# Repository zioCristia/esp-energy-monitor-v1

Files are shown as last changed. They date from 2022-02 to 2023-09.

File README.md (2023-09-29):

# Esp energy monitor - Version 1
### There is a new and better [version](https://github.com/zioCristia/esp-energy-monitor-v2) of this board
Esp32 based module, 220V ac powered, energy monitor with two ct sensors for solar power and home power, and an LCD I2C display for visualization. Integrated with ESPhome in my IoT house based in Home Assistant.
Any possibility of improvement is accepted.

You can find a [video tutorial](https://www.youtube.com/watch?v=UY-CO4Zc2r0) (in italian) of this pcb on YouTube.

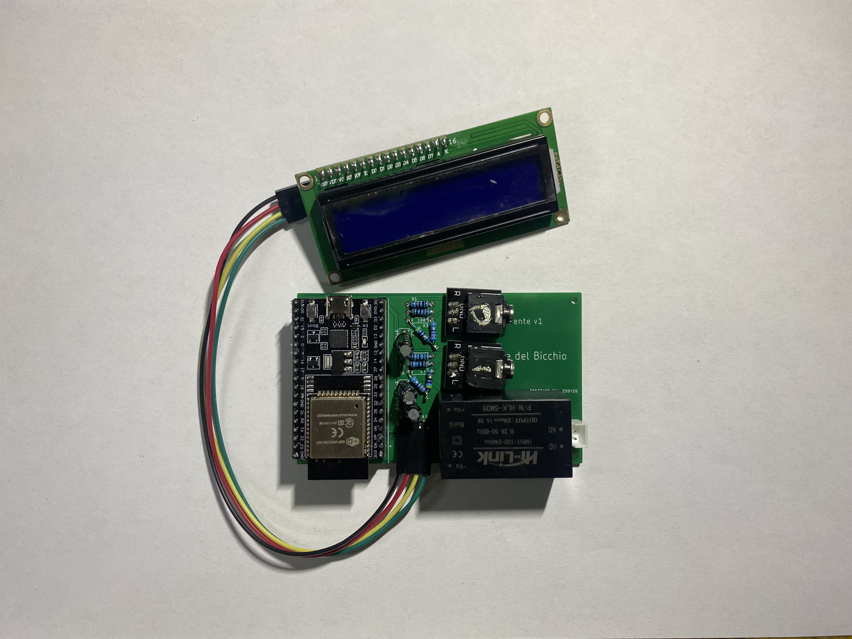
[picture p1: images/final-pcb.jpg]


### Disclaimer! The current pcb design is not the one you can see in the phote above but a new one with jack connectors that are more easily found in the online market. See the [pcb section](#pcb) for more info.

## Table of contents
* [General info](#general-info)
* [Hardware](#hardware)
* [Software](#software)
* [Pcb](#pcb)
* [Contribution](#contribution)

# General info
This is an extremely simple power monitor that I built for my house. It has two ct-sensors which control the current of solar panels production and house consumption. These sensors are controlled by an esp32 board for the connectivity with wi-fi to home assistant thanks to Esphome software. 
The board is powered with a 220v ac, so no external transformer is needed. 

I have also added a 16x2 lcd so that to have an immediate output in my electrical service panel.

You could use this board also if you want to use just on ct-sensor and maybe add it later on. The total cost for a board with two ct sensors (included) is around 20/25€.

In the future I'm planning to add one other ct-sensor for conditioning power consumption and to add an irrigation system for my garden as the current irrigation system controller is near the service panel.



# Hardware
The module is composed of:
* esp32
* sct 013 030 30A/1V as ct sensor, x2
* 16x2 lcd display with i2c interface
* 3.5mm jack connector with 5 pin, x2
* 10k ohm resistor, x4
* 75ohm resistor, x2
* 10uF capacitor, x3

To have the best readings, the 75ohm resistor should be changed based on the max current you are going to measure with the ct sensors, according to the following formula present in [openenergymonitor](https://learn.openenergymonitor.org/electricity-monitoring/ct-sensors/interface-with-arduino) page:
```
Burden Resistor (ohms) = (AREF * CT TURNS) / (2√2 * max primary current)
```
I've used 75 ohm resistor as I'm not going to measure currents higher than 26A.

Of course, if you'd want just one ct sensor and you should use 2x 10k ohm resistors, 75ohm resistor and 10uF capacitor less from the components.
I'm planning to make a version with the normal jack connector directly soldered in the pcb.

You can find some components links [here](https://docs.google.com/spreadsheets/d/1uGH7hN6ZSQ5MoKFjuWFCn1lEjyLJ1oxg2DWpdToigKc/edit?usp=sharing).

# Software
The software used is EspHome in order to integrate the sensor with my HomeAssistant server but you may as well use another software to your liking.

You can find an example of the code I used [here](https://github.com/zioCristia/esp-energy-monitor-v1/blob/main/energy-monitor.yaml.example) or check in the [openenergymonitor](https://learn.openenergymonitor.org/electricity-monitoring/ct-sensors/how-to-build-an-arduino-energy-monitor-measuring-current-only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) site for others examples.

The filter section is used to obtain the right value of current from the sensor. I've done it confronting the values read with a well know source (like a phone or an electric heater).
Moreover I've added a part to read zero values when we are near zero due to some interference that never allows to have values equal to zero.
```
filters:
      - calibrate_linear:
          # Measured value of 0.0065 maps to 0A
          - 0.0065 -> 0
          # Known load: 13.783A
          # Value shown in logs: 0.2348A
          - 0.2348 -> 13.783
      - lambda: |-
          if (x > 0.2) return x;
          else return 0;
```

I've added a software sensor which gives me the difference between the in power and the out power with which I do some automation in home assistant and allows me to maximize the usage of current produced by the solar panels.

The toGridEnergy and the toGridPower is used to interface with the new energy management feature in home assistant.

The lcd prints the solar power as IN, home power as OUT, the hour in the top right and below the difference between IN-OUT, so the differencePower.

# Pcb
The pcb layout is extremely simple with enough space for all the parts. The components are all through hole and the female jack connector is with 5 pins. Anyone can make this pcb at home with just a soldering iron.
As can be seen in the image below, the circuit board has been modified to make it easier to replicate. The jack connector used is more easily found in any store for a few euros. 

You can find the whole eagle project in [this folder](https://github.com/zioCristia/esp-energy-monitor-v1/tree/main/pcb-energy_monitor_v1).

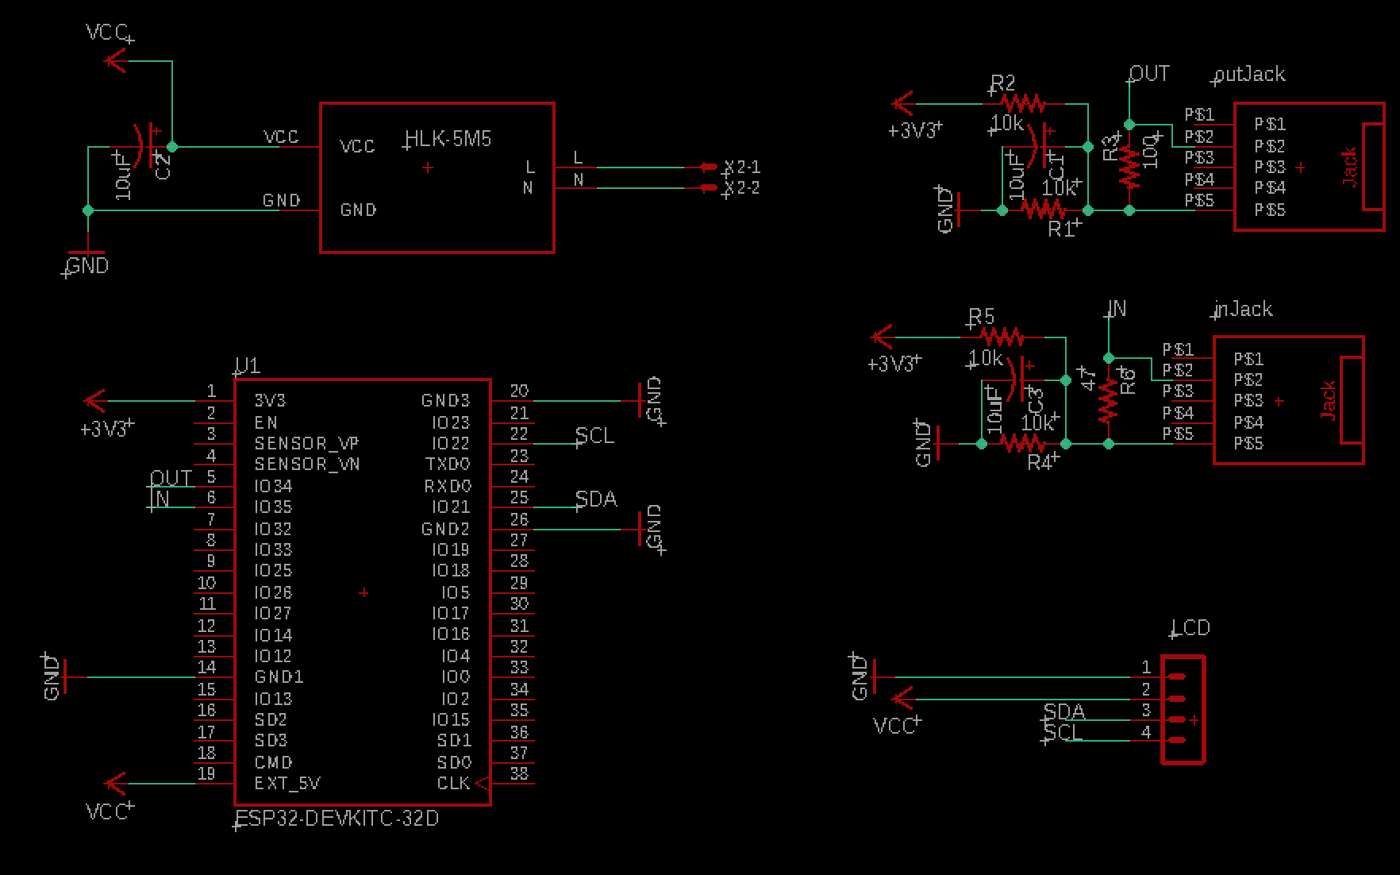
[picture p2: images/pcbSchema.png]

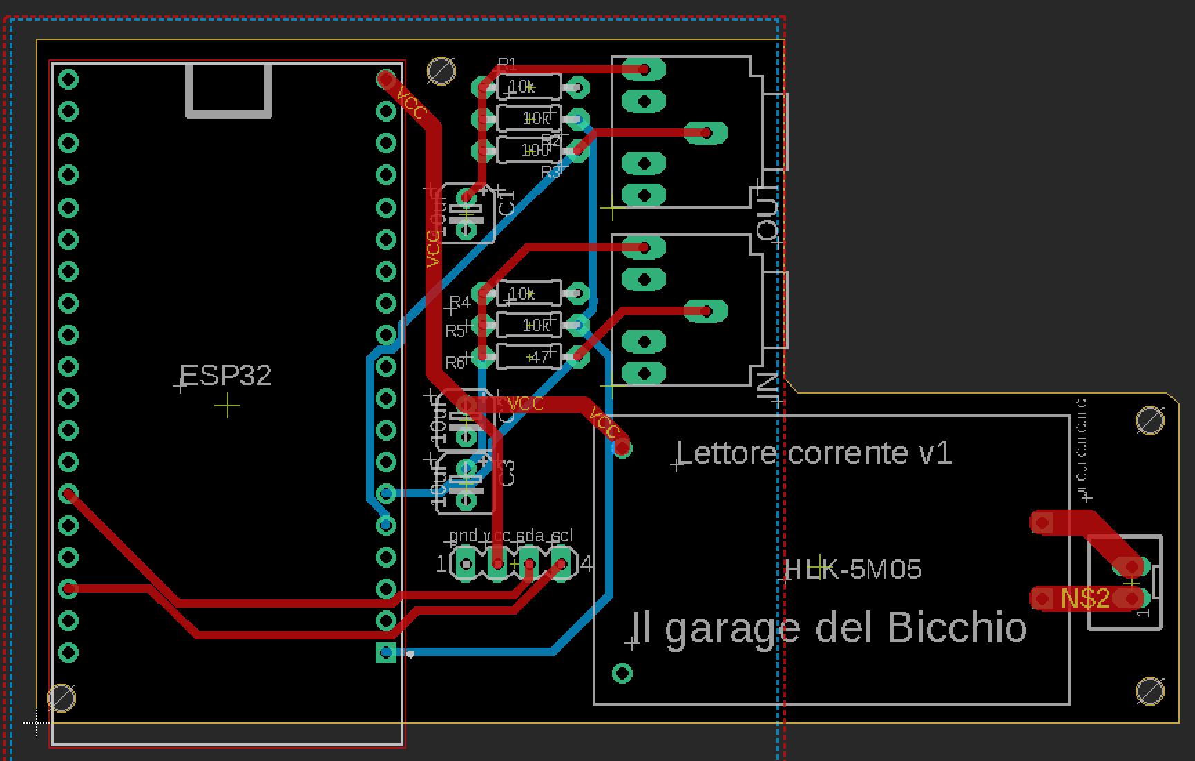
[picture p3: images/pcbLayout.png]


# Contribution
Feel free to report any bugs or feature requests.

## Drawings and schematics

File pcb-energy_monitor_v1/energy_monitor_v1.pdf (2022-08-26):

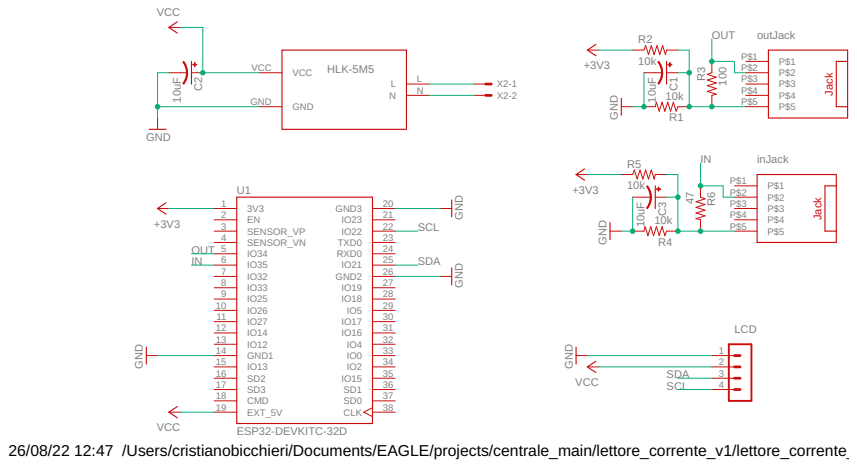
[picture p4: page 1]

26/08/22 12:47 /Users/cristianobicchieri/Documents/EAGLE/projects/centrale_main/lettore_corrente_v1/lettore_corrente_

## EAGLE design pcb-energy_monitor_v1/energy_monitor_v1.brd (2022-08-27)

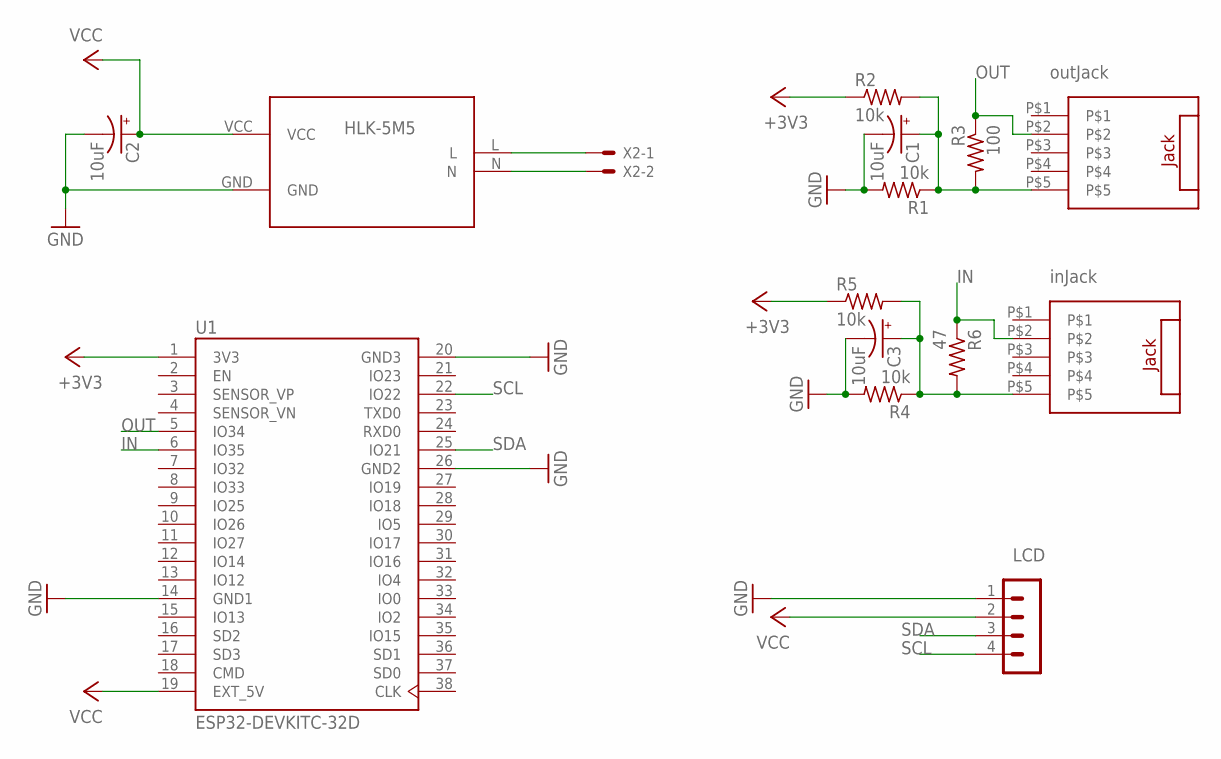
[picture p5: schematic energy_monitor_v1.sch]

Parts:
C1, C2, C3: 10uF; B45181A
HLK-5M5: HLK-5M05; CONV_HLK-5M05
R1, R2, R4, R5: 10k; 0204/7
R3: 100; 0204/7
R6: 47; 0204/7
SV3: MA04-1
U1: ESP32-DEVKITC-32D; MODULE_ESP32-DEVKITC-32D
U$1, U$2: JACK_5PINS
X2: JST-XH-02-PIN-LONG-PAD; JST-XH-02-PACKAGE-LONG-PAD

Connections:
+3V3: R2.1, R5.1, U1.1 (3V3)
GND: C1.-, C2.-, C3.-, HLK-5M5.GND, R1.2, R4.2, SV3.1, U1.14 (GND1), U1.20 (GND3), U1.26 (GND2)
IN: R6.1, U1.6 (IO35), U$2.P$2
unnamed: HLK-5M5.N, X2.2
unnamed: HLK-5M5.L, X2.1
unnamed: C1.+, R1.1, R2.2, R3.2, U$1.P$5
unnamed: C3.+, R4.1, R5.2, R6.2, U$2.P$5
OUT: R3.1, U1.5 (IO34), U$1.P$2
SCL: SV3.4, U1.22 (IO22)
SDA: SV3.3, U1.25 (IO21)
VCC: C2.+, HLK-5M5.VCC, SV3.2, U1.19 (EXT_5V)

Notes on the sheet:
HLK-5M5
inJack
outJack
LCD

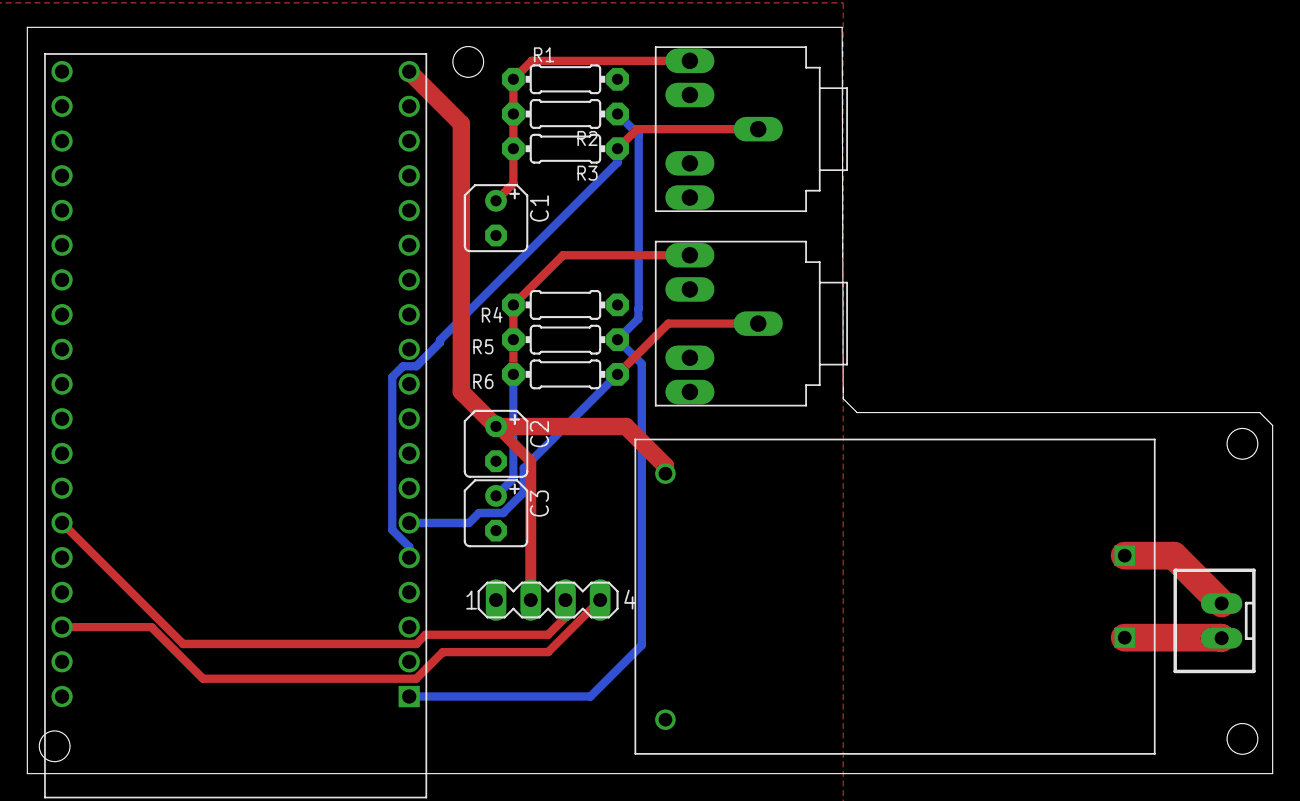
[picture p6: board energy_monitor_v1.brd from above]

Board: 2 copper layers, 91.1 x 54.6 mm, 15 parts (0 on the bottom side), 11 nets.

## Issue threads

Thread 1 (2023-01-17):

Chiarimenti.

cocolino83, 2023-01-17:
Ciao ti avevo scritto su YouTube scrivendoti che volevo realizzare il tuo progetto. Oggi mi sono finalmente arrivati tutti i componenti. Io avrei intenzione di leggere due linee di cosa il piano terra e il secondo piano, ho visto sullo schema del PCB che hai creato che sui jeck hai messo nel primo una resistenza da 100 ohm e nell'altra una da 47 ohm sono un po' confuso. Un'altra domanda i condensatori da 10 uf ma da quanti volt? Ultima domanda il codice va bene quello che hai pubblicato ho andrebbe modificato? Grazie mille 😀
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

zioCristia, 2023-01-26:
Ciao quelle resistenze sono definite "burden resistors" e servono a trasformare il segnale in volt e poter essere letto così da Arduino o altro dispositivo. Il loro valore deve essere calcolato con una formula perché dipendono dal massimo valore di corrente che pensi di dover misurare e dal sensore che hai. Alcuni sensori CT non hanno bisogno di queste resistenze perché sono direttamente con l'uscita in volt, devi vedere quello che hai preso. In ogni modo nel video (https://youtu.be/UY-CO4Zc2r0) spiego meglio come calcolarle o se vuoi più dettagli puoi leggere questa guida: https://docs.openenergymonitor.org/electricity-monitoring/ct-sensors/interface-with-arduino.html

Io i condensatori li ho presi da 50v.

Il codice dovresti modificarlo se non utilizzi il circuito per misurare i valori dei pannelli fotovoltaici e soprattutto se non hai un server HomeAssistant a casa non va bene.

Se hai altre domande scrivi direttamente per email a ilgaragedelbicchio@gmail.com o nei commenti del video di sopra. Sarò più reattivo!

Closed 2023-01-26.
